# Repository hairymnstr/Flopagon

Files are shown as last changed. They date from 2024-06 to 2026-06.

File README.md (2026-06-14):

# Flopagon

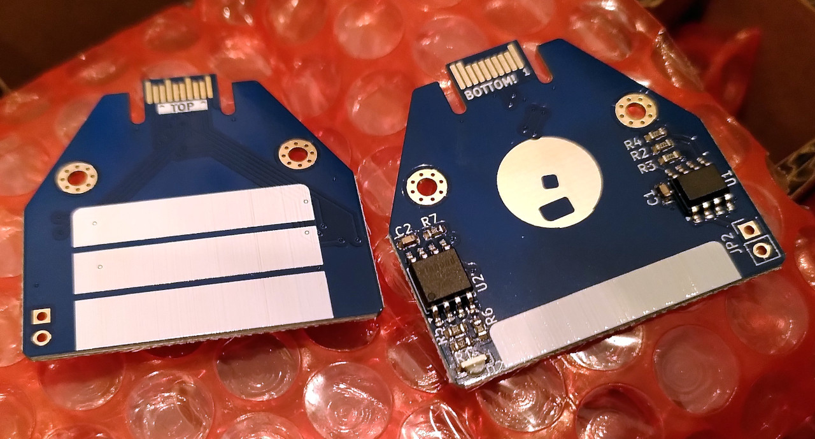
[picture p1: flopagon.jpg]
A blue and white PCB that looks like a floppy disk with two corners trimmed


A 16MB Flash storage solution for the [Tildagon](https://tildagon.badge.emfcamp.org/).  The Flopagon
is styled to look like a classic 3.5" floppy disk but it is functional as well.

## Hardware

### Schematic

There's a PDF of the [schematic](flopagon.pdf)

### Manufacturing files

The files I used to get the boards made and assembled by [JLC PCB](https://jlcpcb.com) are in the `manufacturing/version 1` folder.
The part numbers in the KiCad schematic reference parts from JLC/LCSC which can be used for their assembly service.

### Description

The Flopagon has two chips on it:

#### The EEPROM

There's a small (2kB) EEPROM in line with the [Hexpansion specification](https://tildagon.badge.emfcamp.org/hexpansions/creating-hexpansions/),
this is write protected by default and is designed to have an identity and a small helper app to get the Flopagon up and running.

To write the EEPROM you need to short the two pads of the unpopulated 0.1" header in the corner of the Flopagon.  You can do that easily with a
bit of wire, a pair of tweezers etc.

Flopagon V2 (you can tell it's a V2 because it's black not blue) has an 8kB EEPROM
for a bit of extra space.

#### The Flash Memory

The second chip is a 16MB Flash chip, this connects via an SPI interface using the 4 high-speed I/O pins on the hexpansion interface.
This chip can be formatted with a filesystem and used for storing Python scripts or images, music, data files etc.

## Software

The EEPROM on the Flopagon can be programmed with a simple app that lets you
mount/unmount and format the storage.  Source is in the `app` directory.  To squeeze
the code into the small EEPROM on the original Flopagon it needs to be compiled to
a `*.mpy` file, I've done this already but if you want to modify it you'll need to
do this step.  You need the [mpy-cross](https://pypi.org/project/mpy-cross/) tool
then you can simply run

    mpy-cross app.py

To setup a Flopagon you need to plug it in to your badge and connect to the badge using [mpremote]().  The Tildagon on-board Hexpansion manager will be able to do
this for you soon, but for development reasons you'll still need to follow the steps

On the host change into the `app` directory of a checkout of this repository and run:

    mpremote mount .

This will connect to the running micropython system on your badge, hit `Ctrl-C` to
interrupt the normal OS and get a Python prompt.

    from prepare_eeprom import setup_flopagon

(Obviously import setup_flopagon_v2 if you've got one of the new black ones.  The
only difference is the size of the EEPROM in the header)

Fit the flopagon into a port, they're numbered from 1 clockwise from the top/right 
port.  Short the write-protect jumper, I normally stuff a pair of tweezers in the 
holes.  Now run the command:

    setup_flopagon(2)

The port number needs to be passed, in this example I've used port 2 (right hand
side).  That should do all the formatting and mount and copy the app onto the EEPROM.

Reset the badge to get the hexpansion to do its thing.  It should pop up an app
that lets you mount or format the hexpansion.

## Ideas I've had for using a flopagon

I think with the right code it should be possible to automatically start the Flash chip using a small program on the EEPROM.  From there
you could start launching code from the mounted filesystem so you could have a game that starts when you plug in the Flopagon, like a
cartridge.

Perhaps a file manager app for the badge is required?

Maybe you could put [Doom](https://github.com/espressif/esp32-doom) on a Flopagon?

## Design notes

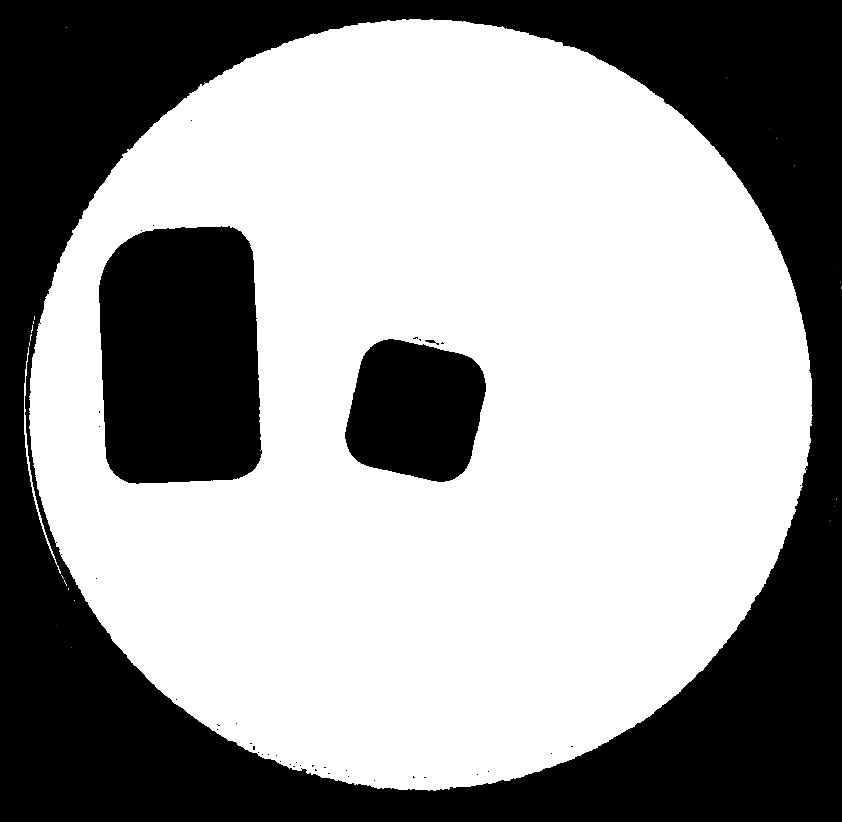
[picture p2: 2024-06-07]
centre.png

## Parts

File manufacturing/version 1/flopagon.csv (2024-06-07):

Comment | Designator | Footprint | LCSC
100nF | C1,C2 | C_0603_1608Metric | C14663
LED_Pad | D2 | LED_1204_Sideview | C5160726
470Ω | R1 | R_0603_1608Metric | C23179
2.2kΩ | R2,R3,R4 | R_0603_1608Metric | C4190
10kΩ | R5,R6,R7 | R_0603_1608Metric | C25804
M24C01-RMN | U1 | SOIC-8_3.9x4.9mm_P1.27mm | C79946
W25Q128JVSIQ | U2 | SOIC-8_5.23x5.23mm_P1.27mm | C97521

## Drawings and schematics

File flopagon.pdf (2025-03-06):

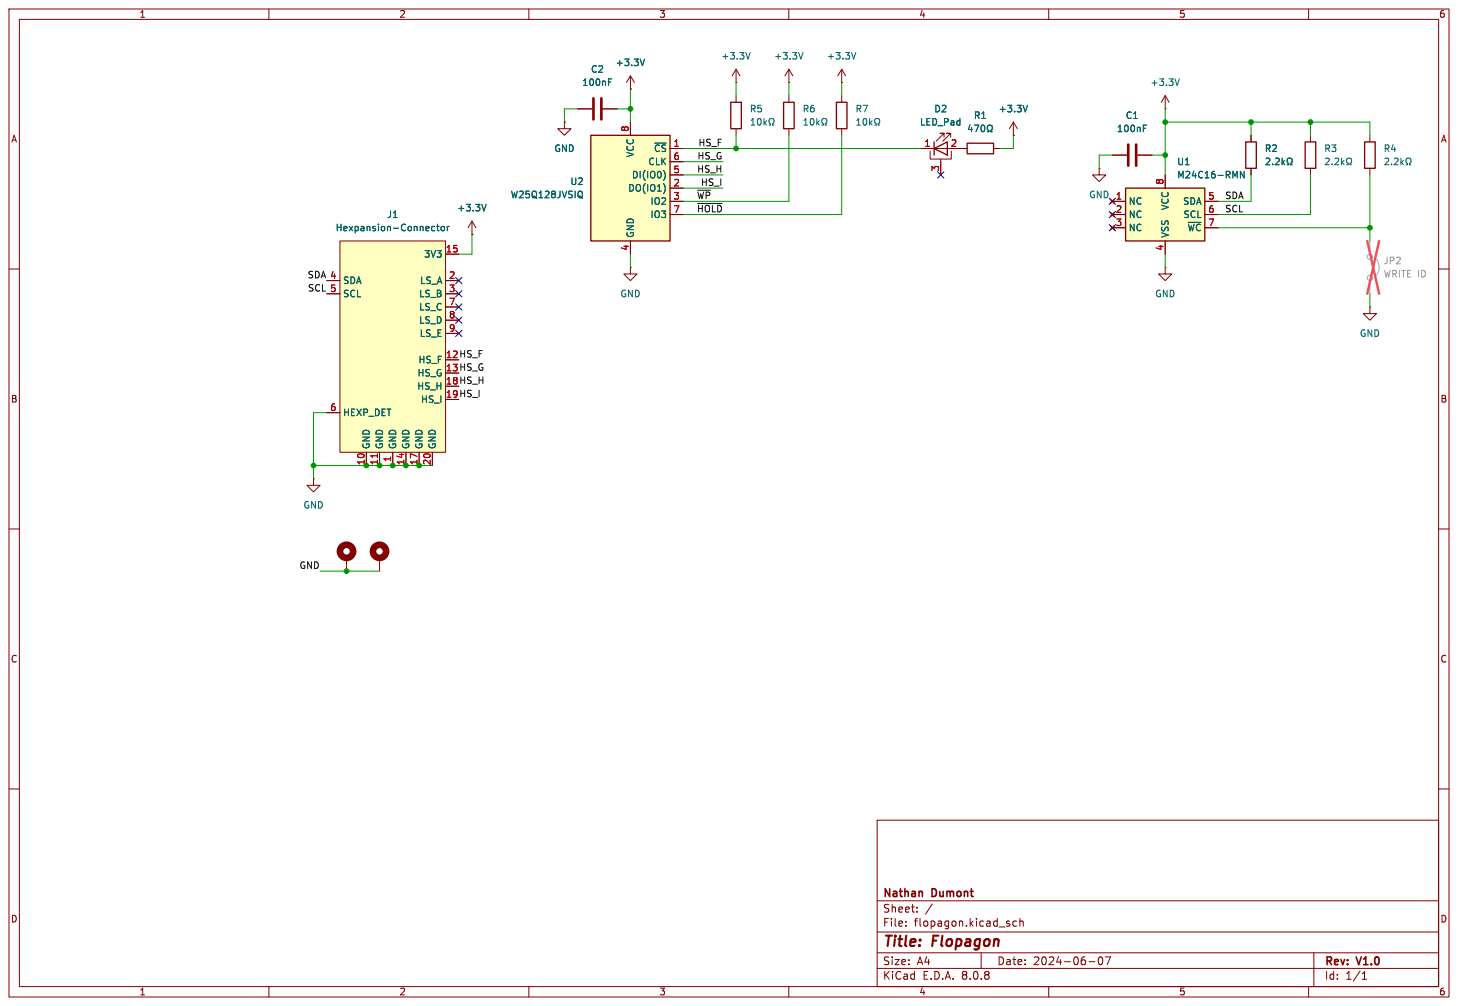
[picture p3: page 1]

4 SDA 5 SCL 6 ~{WC}7 VCC

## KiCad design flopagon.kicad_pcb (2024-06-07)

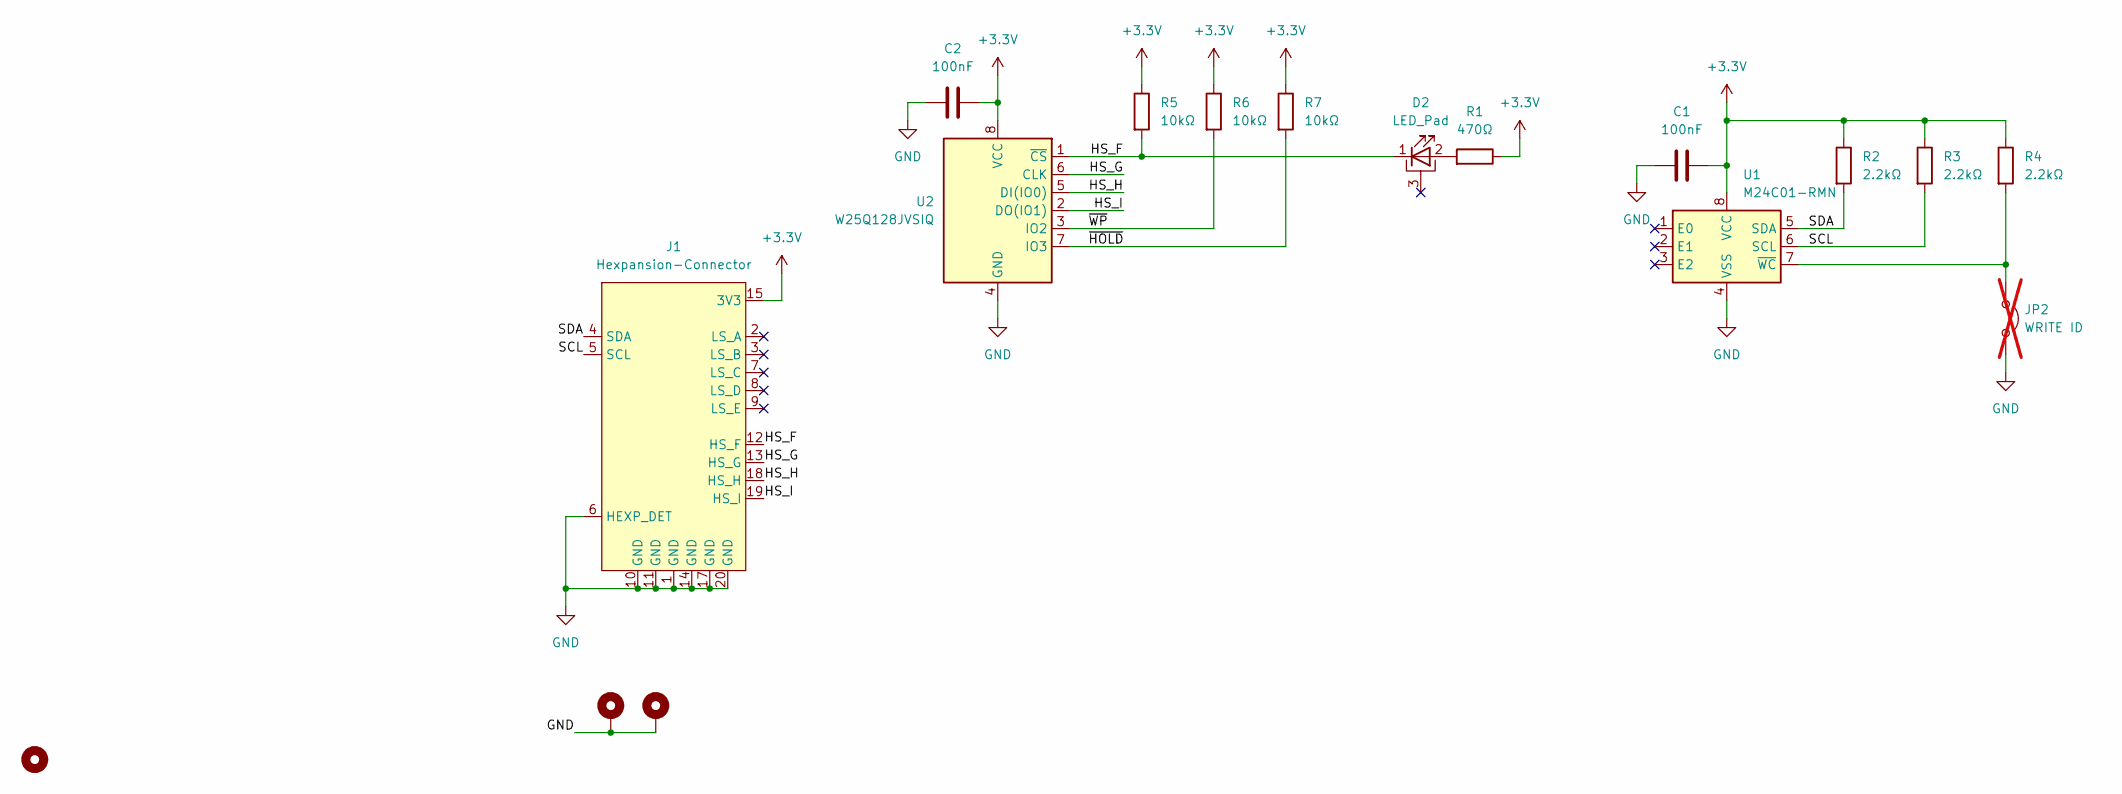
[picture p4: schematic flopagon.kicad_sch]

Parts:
C1, C2: 100nF; C_0603_1608Metric; LCSC C14663
D2: LED_Pad; LED_1204_Sideview; LCSC C5160726
H1, H2: MountingHole_Pad; MountingHole_2.2mm_M2_Pad_Via
H3: MountingHole; floppy_12mm
J1: Hexpansion-Connector; hexpansion-edge-connector
JP2: WRITE ID; PinHeader_1x02_P2.54mm_Vertical; not fitted
R1: 470Ω; R_0603_1608Metric; LCSC C23179
R2, R3, R4: 2.2kΩ; R_0603_1608Metric; LCSC C4190
R5, R6, R7: 10kΩ; R_0603_1608Metric; LCSC C25804
U1: M24C01-RMN; SOIC-8_3.9x4.9mm_P1.27mm; LCSC C79946
U2: W25Q128JVSIQ; SOIC-8_5.23x5.23mm_P1.27mm; LCSC C97521

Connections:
+3.3V: C1.2, C2.2, J1.15 (3V3), J1.16 (3V3), R1.1, R2.1, R3.1, R4.1, R5.1, R6.1, R7.1, U1.8 (VCC), U2.8 (VCC)
/HS_F: D2.1 (K), J1.12 (HS_F), R5.2, U2.1 (~CS)
/HS_G: J1.13 (HS_G), U2.6 (CLK)
/HS_H: J1.18 (HS_H), U2.5 (DI(IO0))
/HS_I: J1.19 (HS_I), U2.2 (DO(IO1))
/SCL: J1.5 (SCL), R3.2, U1.6 (SCL)
/SDA: J1.4 (SDA), R2.2, U1.5 (SDA)
/~HOLD: R7.2, U2.7 (IO3)
/~WP: R6.2, U2.3 (IO2)
GND: C1.1, C2.1, H1.1, H2.1, J1.1 (GND), J1.6 (HEXP_DET), J1.10 (GND), J1.11 (GND), J1.14 (GND), J1.17 (GND), J1.20 (GND), JP2.2 (B), U1.4 (VSS), U2.4 (GND)
unnamed: D2.2 (A), R1.2
unnamed: JP2.1 (A), R4.2, U1.7 (~WC)

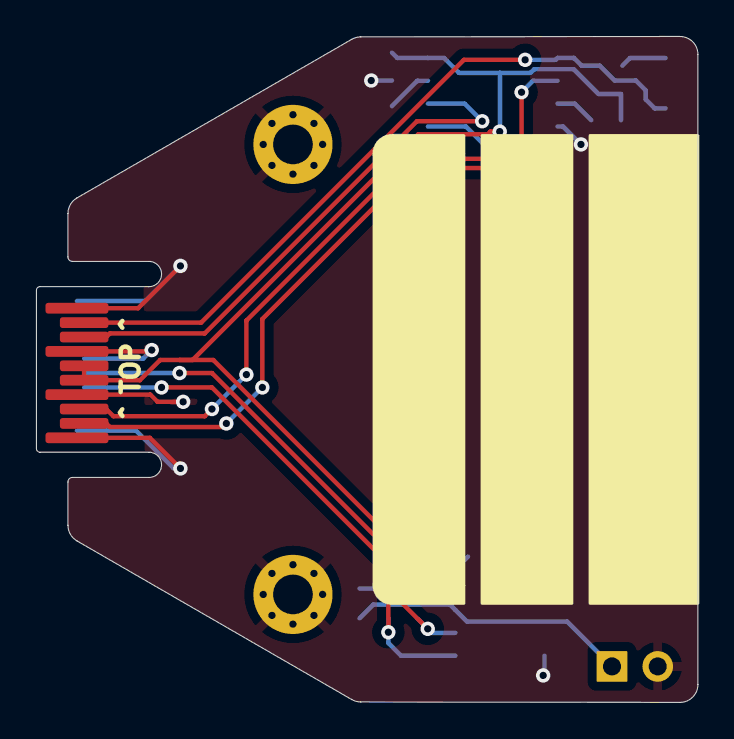
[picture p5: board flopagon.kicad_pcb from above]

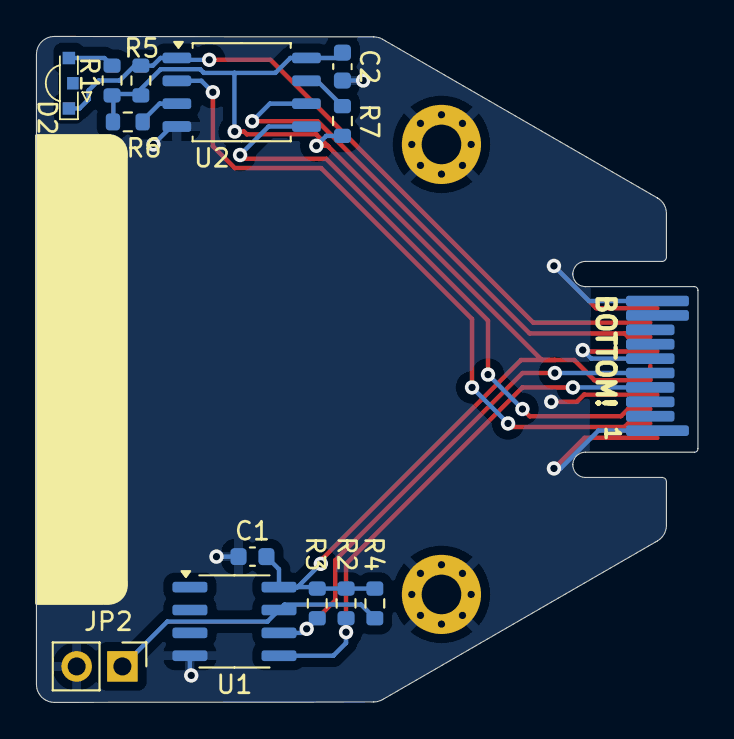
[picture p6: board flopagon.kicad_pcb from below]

Board: 2 copper layers, 36.8 x 37.0 mm, 17 parts (14 on the bottom side), 12 nets.

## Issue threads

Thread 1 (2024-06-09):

Tildagon vs Flopagon! Invalid magic header

andypiper, 2024-06-09:
when the Tildagon starts, it reports:

```
Hexpansion inserted in port: 1
Failed to decode header: Invalid magic in hexpansion header: b'\xff\xff\xff\xff'
```

I'm guessing this is something to do with the EEPROM contents, and probably not an easy fix.

andypiper, 2024-06-09:
Actually, presumably there's a version of [the incantations listed here](https://github.com/walkerdanny/caffeine-jitters?tab=readme-ov-file#note) that [sh|w]ould enable the intended functionality?

andypiper, 2024-06-09:
(I'm thinking, personal webserver with the whole of wikipedia, on flopagon...)

andypiper, 2024-06-09:
(walking NAS, with multiple flopagons...)

hairymnstr, 2024-06-09:
Yeah "Invalid magic" means the EEPROM doesn't have a valid header.  It's because the EEPROMs on the Flopagon's I distributed aren't provisioned.  Mostly this is because there are some issues with the formatting for littlefs on the EEPROM I used.  There's a branch https://github.com/emfcamp/badge-2024-software/tree/eeprom_stuff which has some fixes on it but I still haven't had time to test that branch against other EEPROMs to make sure I'm not breaking other people's hexpansions by fixing this one.

The invalid magic error shouldn't affect your ability to use the Flash memory chip on the hexpansion.

The plan for the Flopagon EEPROM was a tiny app that's in this repo that just helps you format/mount/unmount the Flash but I think the more interesting option is a chain loader that triggers an app from the flash so you can launch into your offline Wikipedia, hitch hikers guide or whatever.

Robotmad, 2024-06-11:
Nathan - we had the same issues with programming EEPROM using the badge software - but have now written a robust app which works with our 64kbit device (it uses 2 address bytes) - using minimal direct I2C access. It scans all hexpansion ports on start up, responds to expansion insertion/removal and offers to program the EEPROM header and then to copy an app over (in our case renaming hexdrive.mpy to app.mpy) Its part of BadgeBot: https://github.com/TeamRobotmad/BadgeBot you are of course most welcome to use any of this code.

hairymnstr, 2024-06-12:
Hi, thanks for the suggestion I will take a look. It sounds very much like the MD Updater that Matthew wrote for his mega drive hexpansion.

The issue isn't the provisioning tool on the badge, it's the low level driver support for the EEPROM I used (even though it's on the recommended list). I'm working to address the issues without breaking support for 16bit addressed EEPROMs here: https://github.com/emfcamp/badge-2024-software/issues/129

Robotmad, 2024-06-12:
Great - there are lots of issues and even some PRs related to the EEPROMs, needs someone to get a grip on it sort in one go - very happy to help test if the EEPROM we've used is different to those you have access to.

It looked to me that there was an update about a month ago which broke write_header for writing to 16-bit EEPROMs, at least ours (probably someone trying to get smaller EEPROMs working).  It split the write into two parts - a) line 101: write the address, b) line 113: write the header - but the first two bytes of the second write are taken as the address again.

Once it has been worked out if an EEPROM is 8 or 16 bit addressing I think there should be a flag remembered for this rather than working it out dynamically all over the place.  Even once you've read the header I'm not sure you can tell from the EEPROM size - isn't it possible to have say 1024bytes either as 8 bit address plus 2 bits in the chip address, or use 10 bits of a 16bit address?
cbarnes@tmsl.com if you want to agree an easier means to chat.

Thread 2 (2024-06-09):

Error creating app

andypiper, 2024-06-09:
Firmware 1.6.0

App fails to start, error at the console is

`Error creating app: function takes 3 positional arguments but 2 were given`

andypiper, 2024-06-09:
Also, I think this is missing `__init__.py` which should be as simple as:

```python
from .app import FlopagonApp
```

hairymnstr, 2024-06-09:
Might be because you've copied the `app.mpy` file instead (or as well as) the `app.py`.

`app.mpy` was a compiled (and therefore smaller) version of the app that fits on the EEPROM (only on the patched eerpom_stuff branch of main firmware).  This only works if it's launched from a hexpansion where the hexpansion port config is passed to the app as an extra argument.

`app.py` has some extra code in that defaults the location to slot 2 if you're running the code from the badge instead of a hexpansion EEPROM so shouldn't throw this error.

The app loading is a bit esoteric but at least on 1.5.0 `app.py` on its own in a folder /apps/flopagon should work.

andypiper, 2024-06-09:
Yes - you're right, I wasn't paying attention and just did a `cp *`, without the `app.mpy` we are all set, Flopagon formats and mounts ✅ thank you!

Closed 2024-06-09.

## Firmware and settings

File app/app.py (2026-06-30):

from lib.flash_spi import FLASH
from system.hexpansion.config import HexpansionConfig
from system.eventbus import eventbus
from machine import SPI
import vfs
import app
import sys
from system.launcher.app import AppDirAddedNotificationEvent, AppDirRemovedNotificationEvent
from app_components import Menu, Notification, clear_background
from system.scheduler.events import RequestForegroundPushEvent

# default location to mount the main flash device
MOUNTPATH = "/flopagon"
APPDIR = "/floppy_apps"

# menu item text for three options
main_menu_items = ["Mount", "Remove", "Format"]

class FlopagonApp(app.App):
    def __init__(self, config=None):
        self.config = config

        # Make a menu GUI widget with the mount, unmount and format options
        self.menu = Menu(self, main_menu_items, select_handler=self.select_handler, back_handler=self.back_handler)

        # create a handle for the notification
        self.notification = None

        # create a flag to request foreground exactly once
        self.foregrounded = False

        # set up the chip select pin, it's the first high-speed IO pin on the hexpansion
        cspin = self.config.pin[0]
        cspin.init(cspin.OUT, value=1)
        self.cspins = (cspin,)

        for _ in range(2):
            # set up the SPI device, we specify all the pins and max out at 10MHz
            # SPI 2 is used for the CTX graphics driver, SPI1 can be used by python code
            self.hspi = SPI(1, 10000000, sck=self.config.pin[1], mosi=self.config.pin[2], miso=self.config.pin[3])

            # Create a handle on the flash object, if you watch the serial console you'll see
            #  1 chips detected. Total flash size 16MiB.
            # at this point if all is working
            try:
                self.flash = FLASH(self.hspi, self.cspins, cmd5=False)
                break
            except ValueError:
                # deinit and try again
                self.hspi.deinit()

        self.mounted = False

        # run the app class init
        super().__init__()

    def deinit(self):
        if self.mounted:
            vfs.umount(MOUNTPATH)
            if MOUNTPATH in sys.path:
                del sys.path[sys.path.index(MOUNTPATH)]
            eventbus.emit(AppDirRemovedNotificationEvent(MOUNTPATH+APPDIR))
            self.mounted = False
            self.hspi.deinit()

    def select_handler(self, item, item_idx):
        # menu handler we try catch this whole thing to keep the code small for embedding in the EEPROM
        try:
            if item == "Mount":
                # mounts the device at the default location
                vfs.mount(self.flash, MOUNTPATH)
                sys.path.append(MOUNTPATH)
                eventbus.emit(AppDirAddedNotificationEvent(MOUNTPATH+APPDIR))
                self.mounted = True
            elif item == "Remove":
                # unmounts (safely removes) the storage
                self.deinit()
            elif item == "Format":
                # Format the drive as FAT
                vfs.VfsFat.mkfs(self.flash)
            # if the try-catch hasn't jumped out yet then what we tried to do must have succeded
            self.notification = Notification(f"{item} succeded")
        except Exception as err:
            # let the user know something went wrong
            self.notification = Notification(f"{item} failed {err}")

    def back_handler(self):
        # no state is saved in the app just minimise when the user is done with their choices
        self.minimise()

    # ctx GUI stuff just taken from the examples
    def draw(self, ctx):
        clear_background(ctx)
        self.menu.draw(ctx)
        if self.notification:
            self.notification.draw(ctx)

    def update(self, delta):
        if not self.foregrounded: # Bring the app to the foreground on first run
            eventbus.emit(RequestForegroundPushEvent(self))
            self.foregrounded = True
        
        self.menu.update(delta)
        if self.notification:
            self.notification.update(delta)

__app_export__ = FlopagonApp

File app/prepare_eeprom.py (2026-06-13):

from machine import I2C
from system.hexpansion.header import HexpansionHeader, write_header
from system.hexpansion.util import (
    detect_eeprom_addr,
    get_hexpansion_block_devices,
    read_hexpansion_header,
)
import vfs
import shutil

# Fill in your desired header info here:
# use this one for the M24C16:
header_flopagon_v1 = HexpansionHeader(
    manifest_version="2024",
    fs_offset=32,
    eeprom_page_size=16,
    eeprom_total_size=1024 * (16 // 8),
    vid=0xCAFE,
    pid=0xD15C,
    unique_id=0,
    friendly_name="Flopagon",
)

header_flopagon_v2 = HexpansionHeader(
    manifest_version="2024",
    fs_offset=32,
    eeprom_page_size=32,
    eeprom_total_size=1024 * (64 // 8),
    vid=0xCAFE,
    pid=0xD15D,
    unique_id=0,
    friendly_name="Flopagon2",
)

def setup_flopagon(port):
    _prepare_generic(port, header_flopagon_v1)

def setup_flopagon_v2(port):
    _prepare_generic(port, header_flopagon_v2)

def _prepare_generic(port, header):
    # Set up i2c
    i2c = I2C(port)

    # autodetect eeprom address
    addr, addr_len = detect_eeprom_addr(i2c)
    print(f"Detected eeprom at {hex(addr)}")

    # Write and read back header
    write_header(
        port, header, addr=addr, addr_len=addr_len, page_size=header.eeprom_page_size
    )
    header = read_hexpansion_header(i2c, addr, set_read_addr=True, addr_len=addr_len)

    if header is None:
        raise RuntimeError("Failed to read back hexpansion header")

    # Get block devices
    eep, partition = get_hexpansion_block_devices(i2c, header, addr, addr_len=addr_len)

    # Format
    vfs.VfsLfs2.mkfs(partition)

    # And mount!
    vfs.mount(partition, "/eeprom")

    # and copy the app
    with open("app.mpy", "rb") as fr:
        with open("/eeprom/app.mpy", "wb") as fw:
            shutil.copyfileobj(fr, fw)

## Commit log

2024-06-07 Finally committing this stuff to Git
    [flopagon.csv, flopagon.kicad_pcb, flopagon.kicad_sch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]
2025-03-06 Updated schematic to make the EEPROM part clearer
    [flopagon.kicad_sch]
